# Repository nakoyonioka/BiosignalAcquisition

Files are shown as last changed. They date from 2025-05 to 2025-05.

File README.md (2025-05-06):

# Multi-Channel Biosignal Acquisition System with DRL

This project provides a hardware platform for capturing physiological signals such as EEG or ECG. It features multiple input channels with dedicated analog signal conditioning stages (amplification, filtering) to prepare the signals for digitization. A key aspect is the inclusion of a Driven Right Leg (DRL) circuit on Channel 1, a common technique in biopotential measurements to improve signal quality by reducing common-mode interference. The system also incorporates robust power management, supporting battery operation and providing necessary regulated voltage rails, before signals are passed to an Analog-to-Digital Converter (ADC) for digital processing via either isolated or non-isolated SPI.

## Features

- **Multi-Channel Input:** Supports acquisition from 4 independent biosignal channels.
- **Analog Front-End:** Each channel includes amplification and filtering stages (high-pass and low-pass filters).
- **Driven Right Leg (DRL):** Channel 1 features a DRL circuit for enhanced common-mode noise rejection.
- **Signal Conditioning:** Band-pass filtering.
- **Analog-to-Digital Conversion:** Utilizes an onboard ADC (**AD7682BCP**) to convert analog signals to digital data.
- **Digital Interface:** Provides SPI communication interface for connecting to a microcontroller or processor. Includes options for isolated or non-isolated SPI.
- **Power Management:**
  - Battery input and switching.
  - Battery protection IC (BQ29723).
  - Boost converter (TPS61232) for generating +5V from a lower battery voltage.
  - RED3025 and LM2776 IC for generating reference voltagse for ADC and opamps
  - Virtual ground generation for the analog circuitry.

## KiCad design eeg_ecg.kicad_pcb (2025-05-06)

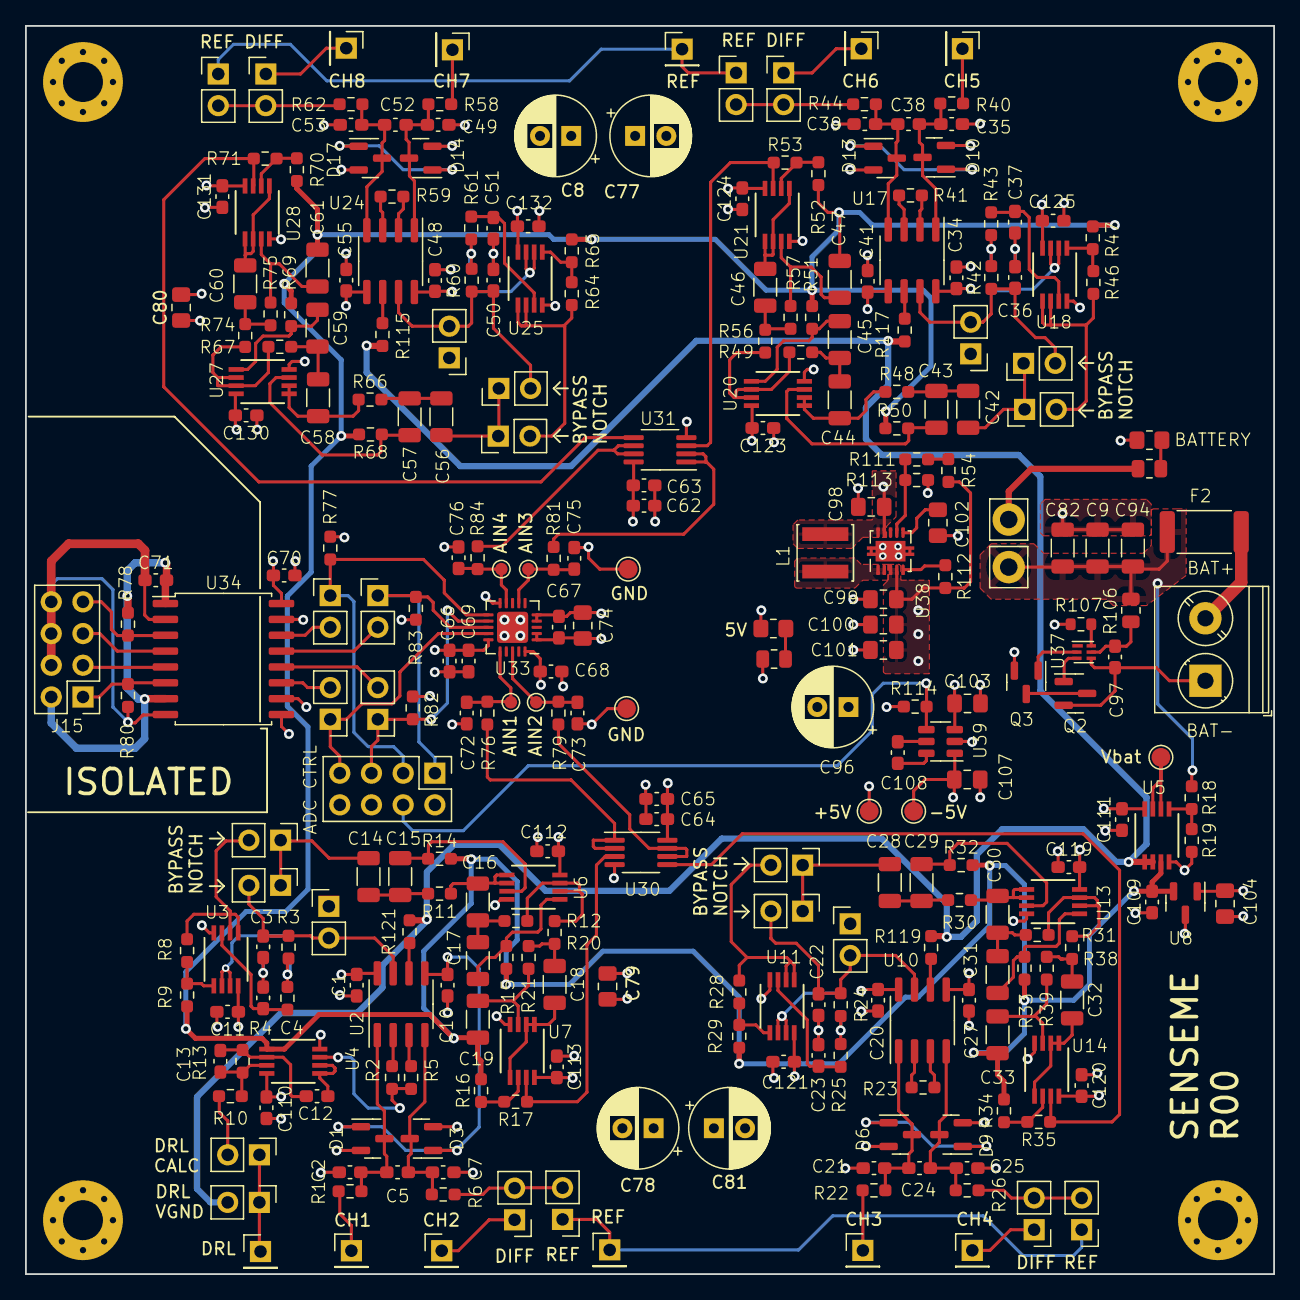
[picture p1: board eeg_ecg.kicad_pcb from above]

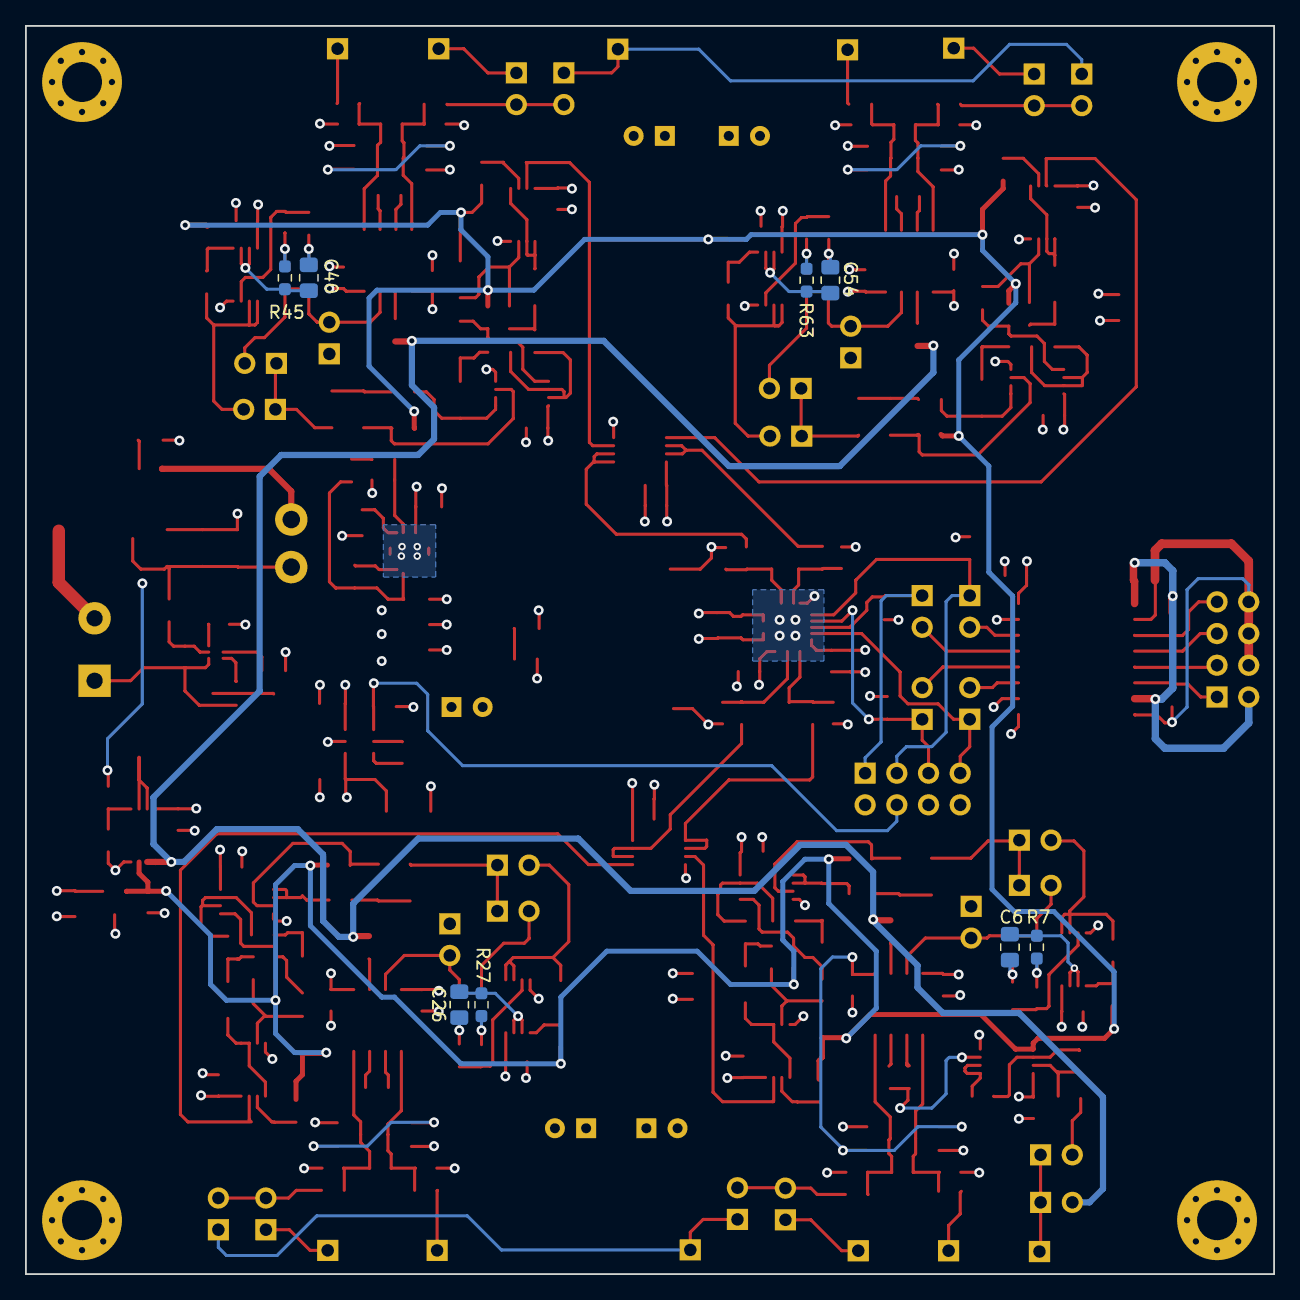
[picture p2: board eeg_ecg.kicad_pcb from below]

Board: 4 copper layers, 100.0 x 100.0 mm, 294 parts (8 on the bottom side), 163 nets.

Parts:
C1, C10, C11, C20, C27, C34, C41, C48, C55, C62, C64, C67, C68, C69, C70, C71, C97, C109, C110, C111, C112, C113, C119, C120, C121, C123, C124, C125, C130, C131, C132: 100nF; C_0603_1608Metric_Pad1.08x0.95mm_HandSolder
C2, C7, C21, C25, C35, C39, C49, C53: 100pF; C_0603_1608Metric_Pad1.08x0.95mm_HandSolder
C3, C4, C5, C22, C23, C24, C36, C37, C38, C50, C51, C52: 1nF; C_0603_1608Metric_Pad1.08x0.95mm_HandSolder
C6, C26, C40, C54: 22nF; C_0805_2012Metric_Pad1.18x1.45mm_HandSolder
C8, C77, C78, C81, C96: 100uF; CP_Radial_D6.3mm_P2.50mm
C9, C82, C94: 22uF; C_1206_3216Metric
C12, C108: 1uF; C_0603_1608Metric_Pad1.08x0.95mm_HandSolder
C13: 220nF; C_0603_1608Metric_Pad1.08x0.95mm_HandSolder
C14, C15, C16, C17, C19, C28, C29, C30, C31, C33, C42, C43, C44, C45, C47, C56, C57, C58, C59, C61: 100nF; C_1206_3216Metric
C18, C32, C46, C60: 220nF; C_1206_3216Metric
C63, C65, C66: 10uF; C_0603_1608Metric_Pad1.08x0.95mm_HandSolder
C72, C73, C75, C76: 10nF; C_0603_1608Metric_Pad1.08x0.95mm_HandSolder
C74: 10uF; C_0805_2012Metric_Pad1.18x1.45mm_HandSolder
C79, C80, C98, C99, C100, C101, C103, C104, C107: 22uF; C_0805_2012Metric_Pad1.18x1.45mm_HandSolder
C102: 10nF; C_0805_2012Metric_Pad1.18x1.45mm_HandSolder
D1, D3, D6, D9, D10, D13, D14, D17: BAV199; SOT-23
D2, D4: GREEN; R_0805_2012Metric_Pad1.20x1.40mm_HandSolder
F2: 5A; R_2512_6332Metric
H1, H2, H3, H4: MountingHole_Pad; MountingHole_3.2mm_M3_Pad_Via
J1, J2, J3, J4, J5, J6, J7, J8, J9, J10, J12: Conn_01x01; PinHeader_1x01_P2.54mm_Vertical
J11, J15: Conn_02x04_Odd_Even; PinHeader_2x04_P2.54mm_Vertical
J29, J30: Conn_01x01_Pin; Pin_D1.4mm_L8.5mm_W2.8mm_FlatFork
J33: Screw_Terminal_01x02; TerminalBlock_Phoenix_PT-1,5-2-5.0-H_1x02_P5.00mm_Horizontal
JP1, JP2, JP3, JP4, JP5, JP6, JP7, JP8, JP9, JP10, JP11, JP12, JP13, JP14, JP15, JP16, JP17, JP18, JP19, JP20, JP21, JP22, JP31, JP32, JP33, JP34: Jumper_2_Open; PinHeader_1x02_P2.54mm_Vertical
L1: SWPA4030S1R0NT/1uH; L_Sunlord_SWPA4030S
Q2, Q3: AO3400A; SOT-23
R1, R6, R18, R19, R22, R26, R40, R44, R58, R62, R77, R78, R80, R82, R83, R114: 10k; R_0603_1608Metric_Pad0.98x0.95mm_HandSolder
R2, R5: 220; R_0603_1608Metric_Pad0.98x0.95mm_HandSolder
R3, R4, R24, R25, R42, R43, R60, R61, R111: 330k; R_0603_1608Metric_Pad0.98x0.95mm_HandSolder
R7, R27, R45, R63: 150k; R_0603_1608Metric_Pad0.98x0.95mm_HandSolder
R8, R28, R46, R64: 20k; R_0603_1608Metric_Pad0.98x0.95mm_HandSolder
R9, R15, R29, R33, R47, R51, R65, R69: 82k; R_0603_1608Metric_Pad0.98x0.95mm_HandSolder
R10, R17, R35, R53, R71, R113: 100k; R_0603_1608Metric_Pad0.98x0.95mm_HandSolder
R11, R30, R48, R66: 30k; R_0603_1608Metric_Pad0.98x0.95mm_HandSolder
R12, R31, R49, R67: 12k; R_0603_1608Metric_Pad0.98x0.95mm_HandSolder
R13, R112: 1Meg; R_0603_1608Metric_Pad0.98x0.95mm_HandSolder
R14, R32, R50, R68: 33k; R_0603_1608Metric_Pad0.98x0.95mm_HandSolder
R16, R34, R52, R70: 1k; R_0603_1608Metric_Pad0.98x0.95mm_HandSolder
R20, R21, R38, R39, R56, R57, R74, R75: 15k; R_0603_1608Metric_Pad0.98x0.95mm_HandSolder
R23, R41, R59: 510; R_0603_1608Metric_Pad0.98x0.95mm_HandSolder
R36, R37, R106: 330R; R_0805_2012Metric
R54: 75k; R_0603_1608Metric_Pad0.98x0.95mm_HandSolder
R76, R79, R81, R84: 100; R_0603_1608Metric_Pad0.98x0.95mm_HandSolder
R107: 2k7; R_0603_1608Metric
R115, R117, R119, R121: 0R; R_0603_1608Metric_Pad0.98x0.95mm_HandSolder
TP1, TP2, TP3, TP4, TP5: TestPoint; TestPoint_Pad_D1.5mm
TP6, TP7, TP8, TP9: TestPoint; TestPoint_Pad_D1.0mm
U2, U10, U17, U24: AD8421ARZ; SOIC-8_3.9x4.9mm_P1.27mm
U3, U4, U5, U6, U7, U11, U13, U14, U18, U20, U21, U25, U27, U28: AD8606ARMZ-R7; AD8606ARMZ
U8: REF3025; SOT-23
U30, U31: ADA4807-2ARM; MSOP-8_3x3mm_P0.65mm
U33: AD7682BCP; LFCSP-20-1EP_4x4mm_P0.5mm_EP2.5x2.5mm
U34: ISO7341C; SOIC-16W_7.5x10.3mm_P1.27mm
U37: BQ29723; WSON-6_1.5x1.5mm_P0.5mm
U38: TPS61230DRC; Texas_S-PVSON-N10_ThermalVias
U39: LM2776; SOT-23-6

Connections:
+5V: C1.2, C8.1, C11.2, C20.2, C34.2, C48.2, C62.2, C63.2, C64.2, C65.2, C66.2, C67.2, C68.2, C69.2, C70.2, C74.2, C77.1, C78.1, C81.1, C96.1, C99.2, C100.2, C101.2, C103.2, C104.2, C110.2, C111.2, C112.2, C113.2, C119.2, C120.2, C121.2, C123.2, C124.2, C125.2, C130.2, C131.2, C132.2, D1.2 (K), D3.2 (K), D6.2 (K), D9.2 (K), D10.2 (K), D13.2 (K), D14.2 (K), D17.2 (K), J11.2, R36.1, R54.1, R77.1, R112.2, R114.1, TP2.1, U2.8 (Vs+), U3.8 (V+), U4.8 (V+), U5.8 (V+), U6.8 (V+), U7.8 (V+), U8.1 (IN), U10.8 (Vs+), U11.8 (V+), U13.8 (V+), U14.8 (V+), U17.8 (Vs+), U18.8 (V+), U20.8 (V+), U21.8 (V+), U24.8 (Vs+), U25.8 (V+), U27.8 (V+), U28.8 (V+), U30.8 (V+), U31.8 (V+), U33.1 (VDD), U33.2 (REF), U33.15 (VIO), U33.20 (VDD), U34.10 (EN2), U34.16 (VCC2), U38.3 (VOUT), U38.4 (VOUT), U39.3 (VIN)
+5VP: C71.2, J15.2, R78.1, U34.1 (VCC1), U34.7 (EN1)
+BATT: C9.1, C82.1, C94.1, F2.2, J29.1, R18.1, R106.2
-5V: C10.2, C27.2, C41.2, C55.2, C79.2, C80.2, C107.2, D1.1 (A), D3.1 (A), D6.1 (A), D9.1 (A), D10.1 (A), D13.1 (A), D14.1 (A), D17.1 (A), TP3.1, U2.5 (Vs-), U10.5 (Vs-), U17.5 (Vs-), U24.5 (Vs-), U39.1 (VOUT)
/ADC and control/ADCCLK: J11.1, JP20.1 (A), R83.1, U33.13 (SCK)
/ADC and control/ADCCSn: J11.3, JP19.1 (A), R77.2, U33.11 (CNV)
/ADC and control/ADCDIN: J11.5, JP21.1 (A), R82.1, U33.12 (DIN)
/ADC and control/ADCDO: J11.7, JP22.1 (A), U33.14 (SDO)
/ADC and control/AIN1: C72.2, R76.1, TP6.1, U33.16 (IN0)
/ADC and control/AIN2: C73.2, R79.1, TP7.1, U33.18 (IN1)
/ADC and control/AIN3: C75.2, R81.1, TP8.1, U33.7 (IN2)
/ADC and control/AIN4: C76.2, R84.1, TP9.1, U33.9 (IN3)
/ADC and control/CH1: R17.1, U7.7, U30.3 (+)
/ADC and control/CH2: R35.1, U14.7, U30.5 (+)
/ADC and control/CH3: R53.1, U21.7, U31.3 (+)
/ADC and control/CH4: R71.1, U28.7, U31.5 (+)
/ADC and control/ISO_CLK: J15.5, U34.4 (INB)
/ADC and control/ISO_CSn: J15.7, R78.2, U34.3 (INA)
/ADC and control/ISO_MISO: J15.1, R80.1, U34.6 (OUTD)
/ADC and control/ISO_MOSI: J15.3, U34.5 (INC)
/Battery input/BATn: C97.2, J33.1, Q2.2 (S), U37.4 (VSS)
/Battery input/BATp: F2.1, J33.2
/Battery input/Vbat: TP1.1, U5.6 (-), U5.7
/Channel 1 with DRL option/DRL: J6.1, JP5.1 (A), JP6.1 (A)
/Channel 1 with DRL option/HPF1: R12.1, R20.2, U6.6 (-), U6.7
/Channel 1 with DRL option/INPUT1: J1.1, R1.1
/Channel 1 with DRL option/INPUT2: J2.1, JP2.1 (A)
/Channel 1 with DRL option/NOTCH1: JP3.2 (B), R8.1, U3.1, U3.2 (-)
/Channel 2/HPF2: R31.1, R38.2, U13.6 (-), U13.7
/Channel 2/INPUT3: J4.1, R22.1
/Channel 2/INPUT4: J5.1, JP8.1 (A)
/Channel 2/NOTCH2: JP11.2 (B), R28.1, U11.1, U11.2 (-)
/Channel 3/HPF3: R49.1, R56.2, U20.6 (-), U20.7
/Channel 3/INPUT5: J7.1, R40.1
/Channel 3/INPUT6: J8.1, JP12.1 (A)
/Channel 3/NOTCH3: JP17.2 (B), R46.1, U18.1, U18.2 (-)
/Channel 4/HPF4: R67.1, R74.2, U27.6 (-), U27.7
/Channel 4/INPUT7: J9.1, R58.1
/Channel 4/INPUT8: J10.1, JP16.1 (A)
/Channel 4/NOTCH4: JP33.2 (B), R64.1, U25.1, U25.2 (-)
/Power supply/EN5V: J11.4, R114.2, U39.4 (EN)
GND: C1.1, C2.1, C7.2, C8.2, C9.2, C10.1, C11.1, C20.1, C21.1, C25.2, C27.1, C34.1, C35.1, C39.2, C41.1, C48.1, C49.1, C53.2, C55.1, C62.1, C63.1, C64.1, C65.1, C66.1, C67.1, C68.1, C69.1, C70.1, C72.1, C73.1, C74.1, C75.1, C76.1, C77.2, C78.2, C79.1, C80.1, C81.2, C82.2, C94.2, C96.2, C98.1, C99.1, C100.1, C101.1, C102.1, C103.1, C104.1, C107.1, C109.1, C110.1, C111.1, C112.1, C113.1, C119.1, C120.1, C121.1, C123.1, C124.1, C125.1, C130.1, C131.1, C132.1, D2.1 (K), D4.1 (K), H1.1, H2.1, H3.1, H4.1, J11.6, J11.8, JP1.1 (A), JP9.1 (A), JP15.1 (A), JP32.1 (A), Q3.2 (S), R19.2, R82.2, R83.2, R107.1, R113.2, TP4.1, TP5.1, U3.4 (V-), U4.4 (V-), U5.4 (V-), U6.4 (V-), U7.4 (V-), U8.3 (GND), U11.4 (V-), U13.4 (V-), U14.4 (V-), U18.4 (V-), U20.4 (V-), U21.4 (V-), U25.4 (V-), U27.4 (V-), U28.4 (V-), U30.4 (V-), U31.4 (V-), U33.4 (GND), U33.5 (GND), U33.10 (COM), U33.21 (EPAD), U34.9 (GND2), U34.15 (GND2), U38.11 (GND), U39.2 (GND)
GNDPWR: C71.1, J15.4, J15.6, J15.8, R80.2, U34.2 (GND1), U34.8 (GND1)
unnamed: C3.2, C4.1, R7.1
unnamed: C6.2, R3.1, R4.2
unnamed: C13.2, R10.2, R13.1, U4.7
unnamed: C14.1, C15.2, R11.2
unnamed: C16.1, C17.2, R12.2
unnamed: C18.1, R20.1, R21.2
unnamed: C22.2, C23.1, R27.1
unnamed: C26.2, R24.1, R25.2
unnamed: C28.1, C29.2, R30.2
unnamed: C30.1, C31.2, R31.2
unnamed: C32.1, R38.1, R39.2
unnamed: C36.2, C37.1, R45.1
unnamed: C40.2, R42.1, R43.2
unnamed: C42.1, C43.2, R48.2
unnamed: C44.1, C45.2, R49.2
unnamed: C46.1, R56.1, R57.2
unnamed: C50.2, C51.1, R63.1
unnamed: C54.2, R60.1, R61.2
unnamed: C56.1, C57.2, R66.2
unnamed: C58.1, C59.2, R67.2
unnamed: C60.1, R74.1, R75.2
unnamed: C2.2, C5.1, D1.3 (common), R1.2, U2.1 (-)
unnamed: D2.2 (A), R36.2
unnamed: C5.2, C7.1, D3.3 (common), R6.2, U2.4 (+)
unnamed: D4.2 (A), R37.2
unnamed: C21.2, C24.1, D6.3 (common), R22.2, U10.1 (-)
unnamed: C24.2, C25.1, D9.3 (common), R26.2, U10.4 (+)
unnamed: C35.2, C38.1, D10.3 (common), R40.2, U17.1 (-)
unnamed: C38.2, C39.1, D13.3 (common), R44.2, U17.4 (+)
unnamed: C49.2, C52.1, D14.3 (common), R58.2, U24.1 (-)
unnamed: C52.2, C53.1, D17.3 (common), R62.2, U24.4 (+)
unnamed: C3.1, JP1.2 (B), JP7.2 (B), R3.2, U2.7
unnamed: JP2.2 (B), JP4.2 (B), R6.1
unnamed: C14.2, JP3.1 (A), JP7.1 (A)
unnamed: JP5.2 (B), R10.1
unnamed: JP8.2 (B), JP10.2 (B), R26.1
unnamed: C28.2, JP11.1 (A), JP13.1 (A)
unnamed: JP12.2 (B), JP14.2 (B), R44.1
unnamed: C22.1, JP9.2 (B), JP13.2 (B), R24.2, U10.7
unnamed: C36.1, JP15.2 (B), JP31.2 (B), R42.2, U17.7
unnamed: JP16.2 (B), JP18.2 (B), R62.1
unnamed: C42.2, JP17.1 (A), JP31.1 (A)
unnamed: JP19.2 (B), U34.14 (OUTA)
unnamed: JP20.2 (B), U34.13 (OUTB)
unnamed: JP21.2 (B), U34.12 (OUTC)
unnamed: JP22.2 (B), U34.11 (IND)
unnamed: C50.1, JP32.2 (B), JP34.2 (B), R60.2, U24.7
unnamed: C56.2, JP33.1 (A), JP34.1 (A)
unnamed: L1.2, U38.1 (SW), U38.2 (SW)
unnamed: Q2.3 (D), Q3.3 (D)
unnamed: Q2.1 (G), U37.3 (Dout)
unnamed: Q3.1 (G), U37.2 (Cout)
unnamed: R2.2, U2.2 (Rg)
unnamed: R5.2, U2.3 (Rg)
unnamed: R23.1, U10.3 (Rg)
unnamed: R23.2, U10.2 (Rg)
unnamed: R41.1, U17.3 (Rg)
unnamed: R41.2, U17.2 (Rg)
unnamed: R59.1, U24.3 (Rg)
unnamed: R59.2, U24.2 (Rg)
unnamed: R54.2, R111.1
unnamed: R121.2, U2.6 (Ref)
unnamed: C4.2, R4.1, U3.3 (+)
unnamed: R8.2, R9.1, U3.5 (+)
unnamed: C6.1, R7.2, U3.6 (-), U3.7
unnamed: R2.1, R5.1, U4.3 (+)
unnamed: C12.2, U4.1, U4.2 (-)
unnamed: C12.1, C13.1, R13.2, U4.6 (-)
unnamed: R18.2, R19.1, U5.5 (+)
unnamed: C15.1, R14.1, U6.3 (+)
unnamed: C16.2, R11.1, U6.1, U6.2 (-)
unnamed: C17.1, R15.1, U6.5 (+)
unnamed: C19.2, R21.1, U7.3 (+)
unnamed: C18.2, U7.1, U7.2 (-), U7.5 (+)
unnamed: R16.1, R17.2, U7.6 (-)
unnamed: R119.2, U10.6 (Ref)
unnamed: C23.2, R25.1, U11.3 (+)
unnamed: R28.2, R29.1, U11.5 (+)
unnamed: C26.1, R27.2, U11.6 (-), U11.7
unnamed: C29.1, R32.1, U13.3 (+)
unnamed: C30.2, R30.1, U13.1, U13.2 (-)
unnamed: C31.1, R33.1, U13.5 (+)
unnamed: C33.2, R39.1, U14.3 (+)
unnamed: C32.2, U14.1, U14.2 (-), U14.5 (+)
unnamed: R34.1, R35.2, U14.6 (-)
unnamed: R117.2, U17.6 (Ref)
unnamed: C37.2, R43.1, U18.3 (+)
unnamed: R46.2, R47.1, U18.5 (+)
unnamed: C40.1, R45.2, U18.6 (-), U18.7
unnamed: C43.1, R50.1, U20.3 (+)
unnamed: C44.2, R48.1, U20.1, U20.2 (-)
unnamed: C45.1, R51.1, U20.5 (+)
unnamed: C47.2, R57.1, U21.3 (+)
unnamed: C46.2, U21.1, U21.2 (-), U21.5 (+)
unnamed: R52.1, R53.2, U21.6 (-)
unnamed: R115.2, U24.6 (Ref)
unnamed: C51.2, R61.1, U25.3 (+)
unnamed: R64.2, R65.1, U25.5 (+)
unnamed: C54.1, R63.2, U25.6 (-), U25.7
unnamed: C57.1, R68.1, U27.3 (+)
unnamed: C58.2, R66.1, U27.1, U27.2 (-)
unnamed: C59.1, R69.1, U27.5 (+)
unnamed: C61.2, R75.1, U28.3 (+)
unnamed: C60.2, U28.1, U28.2 (-), U28.5 (+)
unnamed: R70.1, R71.2, U28.6 (-)
unnamed: R76.2, U30.1, U30.2 (-)
unnamed: R79.2, U30.6 (-), U30.7
unnamed: R81.2, U31.1, U31.2 (-)
unnamed: R84.2, U31.6 (-), U31.7
unnamed: C97.1, R106.1, U37.5 (BAT)
unnamed: R107.2, U37.6 (V-)
unnamed: R111.2, R113.1, U38.7 (FB)
unnamed: R112.1, U38.5 (PG)
unnamed: C102.2, U38.6 (SS)
unnamed: C108.2, U39.5 (C1+)
unnamed: C108.1, U39.6 (C1-)
REFCH: J3.1, J12.1, JP4.1 (A), JP10.1 (A), JP14.1 (A), JP18.1 (A)
VCC: C98.2, J30.1, L1.1, R37.1, U38.9 (EN), U38.10 (VIN)
VPP: JP6.2 (B), R115.1, R117.1, R119.1, R121.1, U5.1, U5.2 (-)
Vdrive: C19.1, C33.1, C47.1, C61.1, C109.2, R9.2, R14.2, R15.2, R16.2, R29.2, R32.2, R33.2, R34.2, R47.2, R50.2, R51.2, R52.2, R65.2, R68.2, R69.2, R70.2, U4.5 (+), U5.3 (+), U8.2 (OUT)
